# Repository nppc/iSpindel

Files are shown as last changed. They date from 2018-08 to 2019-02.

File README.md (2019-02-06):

# iSpindel - *DIY electronic Hydrometer*
# [www.ispindel.de](http://www.ispindel.de)

***
Dashboard
***



***

# Featured in german brewing magazine [Braumagazin.de](http://braumagazin.de/?issue=2018-01)
Braumagazin 1-18 (http://braumagazin.de/?issue=2018-01)

***

If you like that project please vote for the [Hackaday.io *2017 Prize List*](https://hackaday.io/project/20421-ispindel)

Check out [IOT DEVICE PULLS ITS WEIGHT IN HOME BREWING](http://hackaday.com/2017/03/01/iot-device-pulls-its-weight-in-home-brewing/)

## Documentation in other languages

### [English Documentation (work in progress)](docs/README_en.md) :us:
### [Nederlandse Vertaling (lopende werkzaamheden)](docs/README_nl.md) :nl:
### [Documentação em Português (trabalho em andamento)](docs/README_pt.md) :pt:

***

***Say thanks with a beer*** :beers:



***

## [Firmware download here](https://github.com/universam1/iSpindel/releases)

***

## ChangeLog

| Date | Note |
| :--- | :--- |
| 19.12.2018 | Firmware 6.0.4: Higher precision for polynominal possible |
| 19.12.2018 | Firmware 6.0.3: Higher precision for gravity displayed in status page |
| 24.10.2018 | Firmware 6.0.2: Display issues on MacOS resolved |
| 22.08.2018 | **Firmware 6.0.0**:<br>1. Alternative pin for OneWire tempearuture sensor DS18B20 now possible. This allows a different PCB schema to use either pin `D1` or `D6`. <br>2. Auto detection of OneWire pin, successfull detected pin will be saved together with a config `save` action. Output of detailed debug information of OneWire Sensor during searches, helping those with hardware issues. <br>3. Increased battery lifetime of about 20% by reducing the runtime to ~2200ms through various tunings.<br>4. Using *Interrupts* instead of delays to read the Accelerometer, allows significant shorter read intervals <br>5. Shorter read cycles allow  *more precision*, increased samples from 7 to 39 samples that still fit into the necessary wait state for the Temp sensor! |
| 16.08.2018 | Firmware 5.9.1: Fixing Ubidots issue and extending MQTT |
| 09.08.2018 | Firmware 5.9.0: Support for MQTT, InfluxDB (Thanks to jmelhus, iceaway and thorrak) |
| 13.05.2018 | Firmware 5.8.6: allow longer fields for polynominal, SSID and Password |
| 15.03.2018 | Firmware 5.8.5: adding support for Prometheus Pushgateway, thanks to @jankeesv |
| 08.03.2018 | Firmware 5.8.4: adding support for logging temperature data in Fahrenheit and Kelvin, thanks to @iceaway |
| 05.03.2018 | Firmware 5.8.3: Support for InfluxDB as additional backend, thanks to @iceaway |
| 23.02.2018 | New drawer version 'mwx-Edition' using threaded bolt nut and washer - thanks to @mwx |
| 21.02.2018 | Firmware 5.8.2: Extend token size to 40 char to support longer Ubidots token |
| 14.02.2018 | Firmware 5.8.1: HTML encode special character in configuration forms, allows displaying the passwort correctly |
| 09.02.2018 | Firmware 5.8.0: Transmitting the Wifi strength RSSI to insight of the reception |
| 07.02.2018 | Firmware 5.7.1: Allow longer sleep intervals longer up to 99999s == 27 days |
| 03.02.2018 | Firmware 5.7.0: Introduce Factory Reset feature |
| 02.02.2018 | Firmware 5.6.2: Support for Wifi credentials with special characters |
| 07.11.2017 | Firmware 5.6.1: Restoring Wifi credentials, moved to HTTP client library, improved RFCAL resilience to gain more stable Wifi connection |
| 17.10.2017 | Firmware 5.5.4: Various fixes for CraftBeerPi, BrewPiLess and Ubidots |
| 28.09.2017 | Firmware 5.5.0: Recall saved Wifi credential thus persisting over configuration changes |
| 31.08.2017 | iSpindle.py Version 1.3.1: genericTCP Update (local server & prep for public server); Firmware 5.4.2: Memory improvements. |
| 29.08.2017 | Firmware 5.4.1: Rewrite of the upload class to streamline and allow further data items. Also add iSpindel.de as data server as preset. |
| 08.08.2017 | [calibration tool](http://www.ispindel.de/tools/calibration/calibration.htm) to calculate gravity as alternative to the Excel sheet |
| 05.07.2017 | Workaround for BrewPiLess |
| 30.06.2017 | Mentioned in http://preview.mailerlite.com/g6n5p3/660851237247259035/r2w6/ |
| 22.05.2017 | updated build docs |
| 22.05.2017 | switching build environment to platform.io |
| 01.05.2017 | Major Firmware update to 5! Calculate the Gravity now within the iSpindel by expression evaluation! The conversion polynom can be stored per iSpindel and sends as an additional metric (without a unit). Therefore, whether Plato or SG is prefered is up to the user defined polynom. There are two variable available `tilt` and `temp`. Zero point calibration. Firmware update OTA over the Air |
| 12.04.2017 | Mentioned in http://www.homebrewtalk.com/showthread.php?t=598187 |
| 01.03.2017 | Mentioned in hackaday.com http://hackaday.com/2017/03/01/iot-device-pulls-its-weight-in-home-brewing/ |
| 23.02.2017 | English documentation added |
| 14.02.2017 | English documentation added |
| 09.02.2017 | Firmware 4.1.6 |
| 31.01.2017 | Bilder Aufbau Platinenvariante |
| 26.01.2017 | Firmware 4.0: inifinte sleep time developed: the maximum 71min RTC time extends through step-sleeps . Wifi RF calibration introduced when calling configuration. fixed bug of emergency interval. fixed UI numeric formating |
| 25.02.2017 | Firmware 3.5.0: genericTCP: Python Skript um lokal die Daten in eine CSV Datei zu schreiben (thanks to Tozzi) |
| 23.12.2016 | CraftBeerPi Info, FW.3.4.4, Combo-Schlitten |
| 18.12.2016 | FAQ und Ubidots tool |
| 15.11.2016 | Firmware 3.4.2: Supporting now backends: CraftBeerPi, TControl,FHEM, generic HTTP. major Portal rework, added labels for convenience, upload speed improvements, Power saving on empty battery, added custom Battery conversion factor, Bugfixes |
| 11.12.2016 | Sources and drawer online |
| 11.12.2016 | FHEM upload documentation & firmware (thanks @MSBannert!) |
| 07.12.2016 | Schematics |
| 03.12.2016 | Firmware 2.1.2 Wifi improvements |
| 09.11.2016 | Calibration and Excel sheet for conversion to Plato, SG etc. |

***

> Contribution and support is appreciated especially regarding creation and translation of documentation. Feel free to provide a `pull request`.  
>
> Die `iSpindel` befindet sich in andauernder Entwicklung, siehe dazu [den Hobbybrauer.de Thread](http://hobbybrauer.de/forum/viewtopic.php?f=7&t=11235). Mithilfe ist herzlich willkommen und Ergänzungen bitte per Pull Request einreichen. Großes Dank an alle die Unterstützung leisten seitens Grundlagen erarbeiten oder passende Hardware zu finden.

## Inhaltverzeichnis

- [Lizenz](#lizenz)
- [Prinzip](#prinzip)
  - [Metazentrum](#metazentrum)
- [Aufbau](#aufbau)
  - [Varianten](#varianten)
  - [Bauteile](#bauteile)
  - [Schaltplan](#schaltplan)
  - [Schlitten](#schlitten)
- [Konfiguration](#konfiguration)
  - [Ubidots](#ubidots)
  - [Portal](#portal)
  - [Scripting](#scripting)
- [Software](#software)
  - [Firmware Update](#firmware-flashen-from-source)
  - [Compile](#compile-from-source)
- [Anzeige](#anzeige)
  - [Kalibrierung der Spindel](#kalibrierung)
  - [Ubidots Graphen](#ubidots-graphen)
  - [CraftBeerPi](#craftbeerpi)
  - [FHEM](#fhem)
  - [iSpindel TCP Server](#ispindel-tcp-server)
- [FAQ](docs/FAQ.md)
- [Software](#software)

***

## Lizenz

> Jeglicher kommerzieller Nachbau oder Verwendung ist prinzipiell untersagt. Geltende Patente werden verletzt.
>
> All rights reserverd, any commercial use is hereby prohibited and will violate applicable patents.

***

## Prinzip

Die Messung der Dichte von Wasser mit Hilfe des krängenden Zylinders ist so einfach wie genial - man braucht keine externe Referenz (außer der Erde) und der Zylinder ist extrem leicht sauber zu halten. Der Neigungswinkel ändert sich im Verhältnis zum Auftrieb und damit im direkten Zusammenhang mit dem Zuckergehalt.
Kein unnötiges Öffnen zum spindeln und evtl. Kontaminieren!

Kränung

Daher die Idee, ein IoT device mit Wifi zusammen mit einem Beschleunigungssensor und Temperatursensor in einen schwimmenden Zylinder zu legen. Dort wacht er alle bsp. 5min auf, verbindet sich mit meinem Wlan und sendet seinen Neigungswinkel, Temperatur und Akkuspannung an einen Cloudservice wie [Ubidots](www.ubidots.com) oder einen lokalen Server.

### *Metazentrum*

Eigentlich dreht es sich hier um das "Metazentrum", der Zylinder wird solange rotieren bis das Metazentrum im Lot zum Auftriebspunkt ist. Diesen Wert messen wir.

Man kann insofern trimmen, dass man am Boden ein paar Gramm hinzufügt, damit stellt sich der Zylinder mehr auf, oder am Deckel, damit krängt er mehr. 

In der Software berechnent man aus den XYZ Beschleunigungswerten den Euler Winkel für X und Y und bildet daraus den Absolutwinkel. Diesen verrechnen wir mit den kalibrierten Eckwerten zum °Plato.

***

## Aufbau

### Varianten

> Alle drei Varianten sind funktionell identisch

1. [Variante A: Lochrasterplatine & Schlitten](docs/iSpindelbreadboard.md)  
Die Lochrasterplatine ermöglicht den Nachbau jederzeit mit 'Hausmitteln' 
1. [Variante B: nur Platine](docs/iSpindelPCB.md)  
Die fertige Platine über die Sammelbestellung bringt einen komfortablen Aufbau
1. [Variante C: Platine & Schlitten](docs/iSpindelPCB.md)  
Die obige Platine kann (über Trenn-Schnitt) mit dem Kunstoff Schlitten in Kombination verwendet werden der einen spielfreien Sitz garantiert.

### Bauteile

***siehe [Bauteile](docs/Parts.md)***

### Schaltplan

***siehe [Schaltplan](docs/Schaltplan.md)***

### Schlitten

***siehe [Bauteile](docs/Parts.md)***

***

## Konfiguration

### Ubidots

- Zu Beginn muss ein kostenloser Account bei [Ubidots.com](https://ubidots.com) erstellt werden
- Im Menü  `API Credentials` erhält man seinen `Token` durch das die iSpindel die Berechtigung zum Schreiben der Daten erhält.  
***Diesen notieren.***  

Token

### Portal

Durch mehrmaliges Drücken der `Reset Taste` erstellt der Wemos einen AccessPoint, mit dem verbunden man die nötigen Einstellugen vornehmen kann.

> Die `iSpindel` signalisiert dass sie sich im *Konfiguration-Modus* druch permanentes Blinken im Sekundentakt.  
Man verlässt den *Konfiguration-Modus* durch speichern seiner Einstellungen, durch betätigen des Menüpunkts `Start iSpindel` oder durch warten von 5 Minuten. Danach befindet sie sich im *Betriebsmodus* d.h. sie sendet ihre Daten und geht daraufhin direkt in den "Deep Sleep" Standby Modus. Daher ist sie im normalen Modus nicht erreibar.

- Der Ubidots  `Token` ~~und die  `IDs`~~, welche man oben notiert hat, werden nun an dieser Stelle eingetragen.  

- Ebenfalls stellt man hier den `Intervall` ein in dem sie Daten liefert. Dies hat direkt mit der Akku Lebensdauer zu tun. Es empfiehlt sich in der Praxis etwa `1800` Sekunden (= 30 Minuten) Takt zu wählen.

   Setup

- Man erreicht es über

   AccessPointPortal

- Eine Übersicht der Daten kann man über den `Info` Menüpunkt einsehen

  Info

Nach dem man obige Daten eingetragen und gespeichert hat, wird die Spindel sich mit dem Wlan und Ubidots verbinden und die Daten übertragen.  
Falls noch nicht vorhanden, wird selbständig ein neues `Device` erstellt und die Sensoren angelegt.  
Auf der Ubidots Weboberfläche wird man nun unter `Sources` sehen dass die Daten aktualisiert werden.  

Nun kann man im `Dashboard` sich seine Graphen nach Belieben zusammenstellen.

### Scripting

Ubidots kann ausserdem an vielen Stellen per Script bedient werden. Eine Dokumentation zu den Funktionen findet sich direkt bei Ubidots. Hiermit können zum Beispiel nicht mehr benötigte Daten in Variablen gelöscht werden.

- [siehe Ubidots-Scripting](docs/ubidotsscripting.md)

***
## Anzeige

Die `iSpindel` kann ihre Daten an verschieden backends senden. Es empfiehlt sich mit dem Cloudservice [Ubidots](www.Ubidots.com) zu beginnen, dort kann man sich einen kostenlosen Account erstellen und die Graphen sich darstellen. Man kann auch weitere Abwandlungen der Daten vornehmen, wie den Plato / SG Wert errechnen, den EVG usw.
Folgende backends werden mittlerweile unterstützt:

### Ubidots Graphen

- [Plato Formel](docs/Kalibrierung.md#formel)

### CraftBeerPi

> Beschreibung von @not:  
*Wenn Du die neueste Firmware auf Deine iSpindel geflasht hast musst Du auch craftbeerpi updaten: dazu brauchst Du den branch "hydrometer". Wenn Du die Spindel dann konfigurierst, gibst Du neben den Einstellungen für Dein WLAN im Dropdown-Menu "CraftbeerPi" an und darunter die IP Adresse Deines im selben Netzwerk gelegenen Craftbeerpi-Servers.
Danach sendet die Spindel an den Raspberry Pi -Rechner und Craftbeerpi registriert die Spindel automatisch . Wenn die Verbindung klappt, findest Du die Spindel "wie von Geisterhand" in der Hardware-Konfiguration von CBP.
Du siehst, dass Daten ankomen, wenn Du Deine Fermentation / Gärung im CBP anschaust, da sind dann nicht nur die Temperatur (ist und soll) , sondern auch Spindeltemperatur und Plato zu sehen (siehe Screenshot oben) mit letztem Zeitstempel.*  
`git clone -b hydrometer https://github.com/Manuel83/craftbeerpi.git`

### FHEM

- [upload zu FHEM](docs/upload-FHEM.md)

### iSpindel-TCP-Server

- [https://github.com/DottoreTozzi/iSpindel-TCP-Server](https://github.com/DottoreTozzi/iSpindel-TCP-Server)

***

## Kalibrierung

Zur Umrechnung von dem gemessenen **Winkel ° in °Plato, SG, %mas** o.ä. ist es initial nötig eine Referenzkurve zu kalibrieren. 
Die gewonnenen Referenzen können dann über eine Excel Tabelle oder das [Online Gravity Calibration tool](http://www.ispindel.de/tools/calibration/calibration.htm) in eine Funktion überführt werden, die zur Darstellung hinterlegt wird. 

Da jede selbstgebaute Spindel andere Messwerte ergeben wird, muss man diesen Prozess einmalig pro iSpindel durchführen.

[siehe Kalibrierung durchführen](docs/Kalibrierung.md)

***

## Software 

### Firmware flashen

- [Firmware flashen](docs/Firmware.md)

### Compile from Source

- [Compile from source](docs/compile.md)

***Gefällt es dir, na dann spende mir halt ein Bier***  :beers:



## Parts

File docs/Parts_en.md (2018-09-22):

# Parts

Following parts are required:

### Plastic cylinder

- plastic cylinder `Petling` [Petling-XL](http://cachers-world.de/de/Petling-XL)
> The provider [cachers-world.de](http://cachers-world.de/de/Petling-XL) supports this project by providing the appropriate petling in the long term and using the coupon code "` HOBBYBRAUER` "( Capitalization!) 20% discount granted.
This [Petling-XL](http://cachers-world.de/de/Petling-XL) fits the 3D printed sled.

***

### drawer

- plastic drawer [download](https://github.com/universam1/iSpindel/raw/master/drawer/)

This is also offered by an online dispatch

***https://3d-mechatronics.de/en/ispindel-diy-set-komplett_151.html***

> *** There is no business relationship between me and the provider, this is a pure help. ***

Sled
***
### Battery pack

- `18650 LiIo cell` (e.g.,` Panasonic NCR18650B`)

***

### Components

- [Wemos D1 mini](https://wiki.wemos.cc/products:d1:d1_mini)
- `GY-521` Gyro & Acceleration Sensor (MPU-6050 on suitable breakout board)
- [DS18B20 Temperature Sensor](https://www.maximintegrated.com/en/products/analog/sensors-and-sensor-interface/DS18B20.html)
- Square grid 3x4cm or printed circuit board
- Resistors
  - 4k7 ohms
  - 220k ohms
  - 330 ohms or BAT43 diode
- [microswitches](http://www.reichelt.de/Schiebeschalter/SS-ESP201/3/index.html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)
Or at the PCB [Reed Wechsler](http://www.reichelt.de/Reedrelais/KSK-1C90/3/index.html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)
- Lipo charger `TP4056` (6 pin recommended)

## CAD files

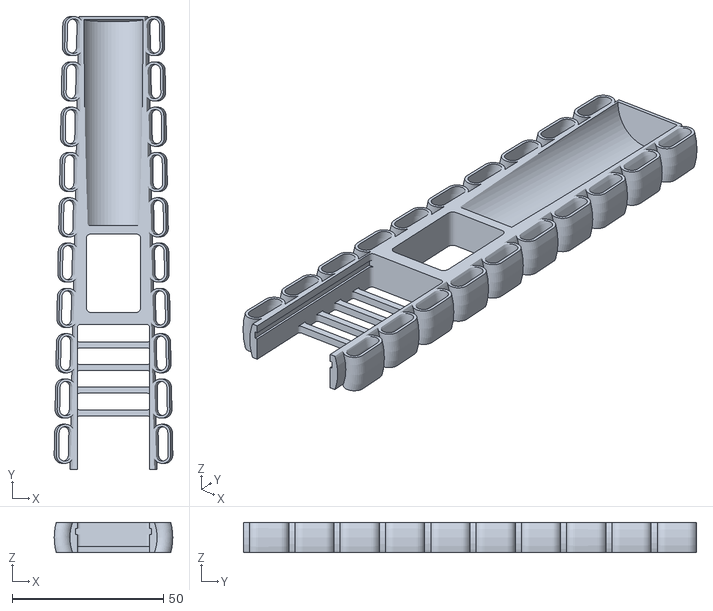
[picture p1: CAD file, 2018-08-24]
drawer/25mmPCB/Sled.stl
39.3 x 150.0 x 10.0

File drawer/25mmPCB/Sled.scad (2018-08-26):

// PCB is 25x48mm

$fn = 80;
length = 148; // normally is 150, but I have too much weight at the end, so it doesn't fit.
diamchange = 2.73; // smaller 4mm each 10cm
diam1 = 40.1;
diam2 = diam1-(length/100*diamchange); 
echo(diam1);
echo(diam2);


difference(){
    mainpart();
    translate([0,99,-15])cube([50,200,20],true);
    translate([0,99,15])cube([50,200,20],true);
    CutOut(24,53*2,2);
    translate([0,47.5/2+5,2])cube([25.3,48.5,1.85],true); // for PCB
    translate([0,147,2])rotate([86,0,0])liion(); //battery
    translate([0,66,0])CutOut(22,23,4);
}
translate([0,42,-5])underPCB();


module liion(){
    cylinder(d=19.5,h=68,$fn=50);
}


module roundcut(radius, width, rlen){
    minkowski(){
    union(){
        difference(){
            cylinder(r=radius,h=20,$fn=50);
            translate([0.2,-width+1.5,0])cylinder(r=radius,h=20,$fn=50);
            translate([rlen-1.5,-radius,0])cube([radius*2,radius*2,20]);
            translate([-radius*3,-width,0])cube([radius*3,radius*3,20]);
        }
    }
    cylinder(d=1.5,h=20,$fn=15);
    }
}

module CutOut(cw,cl,cdiam) {
  cwd=cw-cdiam;
  clw=cl-cdiam;
  hull(){
    translate([cwd/2,clw/2,0])cylinder(d=cdiam,h=20,$fn=20,center=true);
    translate([-cwd/2,clw/2,0])cylinder(d=cdiam,h=20,$fn=20,center=true);
    translate([cwd/2,-clw/2,0])cylinder(d=cdiam,h=20,$fn=20,center=true);
    translate([-cwd/2,-clw/2,0])cylinder(d=cdiam,h=20,$fn=20,center=true);
  }
}

module underPCB(){
    difference(){
        translate([0,1,1])cube([25,22,2],true);
        for(i=[0:7.5:27])translate([0,i-17,0])CutOut(24,5.5,1.5);
    }

}

module donut(diamext,diamint){
    rotate_extrude(convexity = 10)
    translate([(diamext-(diamext-diamint)/2)/2, 0, 0])
    circle(d = (diamext-diamint)/2, $fn = 30);
}


module mainpart() {
  translate([0, length, 0]) 
  rotate([90, 0, 0])
  union() {
    cylinder(d2=diam1-11,d1=diam2-11, h=length);
    for(i=[0:16.5:140])
       translate([0,0,i])spring(diam2+(i/100*diamchange),14,5.5,0.8);
  }
}

module spring(sdiam, slen, sh, thck){
    difference(){
        spring_sub(sdiam,slen,sh);
        translate([0,0,thck])spring_sub(sdiam-thck*2,slen-thck*2,sh-thck*2);
    }
}
    
module spring_sub(sdiam,slen,sh){
    sdiam2 = sdiam-((slen-sh)/100*diamchange);
    difference(){
        translate([0,0,sh/2])cylinder(d2=sdiam, d1=sdiam2,h=slen-sh);
        translate([0,0,sh/2])cylinder(d2=sdiam-sh*2, d1=sdiam2-sh*2,h=slen-sh);
    }
    translate([0,0,sh/2])donut(sdiam2,sdiam2-sh*2);
    translate([0,0,slen-sh/2])donut(sdiam,sdiam-sh*2);
}

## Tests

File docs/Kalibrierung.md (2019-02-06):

# Kalibrierung

>Zur Umrechnung von Winkel ° in °Plato, SG, %mas o.Ä. ist es initial nötig eine Referenzkurve zu kalibrieren. Die gewonnenen Referenzen können dann vereinfacht über eine Excel Tabelle in eine Funktion überführt werden, die zur Darstellung hinterlegt wird. Da jede selbstgebaute Spindel andere Messwerte ergeben wird, muss man diesen Prozess einmalig durchführen.

>Stelle sicher dass die iSpindel im normalen Wasser ca. 25° Neigung von der Vertikalen aufweist. Gegebenenfalls noch weiter austarieren. Meistens sind ca. 20g an zusätzlichem Gewicht nötig.

***

# Inhalt

- [Kalibrierung](#kalibrierung)
- [Inhalt](#inhalt)
  - [Variante A (vereinfacht)](#variante-a-vereinfacht)
  - [Variante B Schnellvergärung (genauer)](#variante-b-schnellverg%C3%A4rung-genauer)
  - [Variante C Referenzen ziehen (empfohlen)](#variante-c-referenzen-ziehen-empfohlen)
- [Formel](#formel)
- [Speichern](#speichern)
  - [in iSpindel hinterlegen](#in-ispindel-hinterlegen)
  - [Alternativ: in Ubidots nach-berechnen](#alternativ-in-ubidots-nach-berechnen)

***

## Variante A (vereinfacht)

> Zum Ablessen des Neigungswinkels empfiehlt es sich, die iSpindel mit Ubidots zu verbinden und einen sehr kurzen Intervall (20 Sekunden) zu setzen. Damit kann die Neigung über die Webseite verfolgt werden.  
>  
>  Alternativ: Im Konfigurationsmodus kann die ```Info``` Seite aufgerufen werden und dort den Winkel abgelesen werden.

1. iSpindel in Reinwasser 0 °Plato legen, ***Winkel notieren (sollte ca. 25° Neigung aus der Vertikalen sein)***
2. Zuckerwasser mit ca. 20 °Plato herstellen, oder höchsten Wert den man voraussichtlich erreichen wird. ***Plato messen und Winkel notieren***  
*Beispiel 400ml Wasser + 100g Kristallzucker auflösen*
1. Wasser weiter verdünnen auf ca. 15 °Plato, ***Plato messen und Winkel notieren***   
*Beispiel +166ml Wasser hinzufügen*
1. Wasser weiter verdünnen auf ca. 10 °Plato, ***Plato messen und Winkel notieren***   
*Beispiel +333ml Wasser hinzufügen*
1. Wasser weiter verdünnen auf ca. 7,5 °Plato, ***Plato messen und Winkel notieren***   
*Beispiel +333ml Wasser hinzufügen*
1. Wasser weiter verdünnen auf ca. 5 °Plato, ***Plato messen und Winkel notieren***   
*Beispiel +666ml Wasser hinzufügen*
1. Wasser weiter verdünnen auf ca. 2,5 °Plato, ***Plato messen und Winkel notieren***   
*Beispiel +2000ml Wasser hinzufügen*

**gemessene Werte werden in das [Excel Sheet](#formel) eingetragen** 

***

## Variante B Schnellvergärung (genauer)

**Diese Variante ist genauer, da der CO2 Auftriebsfehler mit ein - kalibriert wird**

> Zum Ablessen des Neigungswinkels empfiehlt es sich, die iSpindel mit Ubidots zu verbinden und einen sehr kurzen Intervall (20 Sekunden) zu setzen. Damit kann die Neigung über die Webseite verfolgt werden.  

1. iSpindel in Reinwasser 0 °Plato legen, ***Winkel notieren (sollte ca. 25° Neigung aus der Vertikalen sein)***
1. Zuckerwasser mit ca. 20 °Plato herstellen, oder höchsten Wert den man voraussichtlich erreichen wird.  
*Beispiel 800ml Wasser + 200g Kristallzucker auflösen*
1. Hefe hinzufügen und Spindel einlegen. ***Plato messen und Winkel notieren*** 
1. bis x. :  Nun nimmt man regelmässig Plato Messwerte und den jeweilig korrelierenden Winkel und trägt dies in die Excel Tabelle ein. 
> Achtung: Sollte man hier einen Refraktometer verwenden darf man die Korrektur dessen nicht vergessen: [Refraktometerrechner](http://www.maischemalzundmehr.de/index.php?inhaltmitte=toolsrefraktorechner)

## Variante C Referenzen ziehen (empfohlen)

> Die einfachste und vermeintlich genaueste Variante ist sie in eine Gärung zu bringen und einige Referenzen zu ziehen. Man notiert sich die Stammwürze und den entsprechenden Winkel den man zB. bei Ubidots zu diesem Zeitpunkt sieht. Im Verlauf der Gärung nimmt man weiter 3 oder mehr solcher Referenzen ( gespindelte Stammwürze / Winkel ) notiert diese bis zum Gärende. Damit erhält man praxisnahe Werte die übrigens den CO2 Einfluss beinhalten bzw. berücksichtigen.
Danach kann man mit dem errechnen der Formel fortfahren, und diesen fest in der iSpindel dann hinterlegen.

***

# Formel
Folgende Varianten existieren um das Polynome leicht zu errechnen:

- ## [Online Gravity Calibration tool](http://www.ispindel.de/tools/calibration/calibration.htm)

Die Messwerte werden in das Feld `Plato` oder `Brix` eingetragen mit dem korrespondierendem Neigungswinkel unter `Tilt`. Daraus errechnet sich dann ein Polynom 2. oder 3. Grades welches dann in der Firmware hinterlegt wird.

***

- ## Excel Tabelle

> Obige Meßwerte können nun anhand dieser Excel Tabelle in eine annähernde Formel überführt werden.  
Diese hinterlegt man in Ubidots um die Anzeige des °Plato zu erhalten.  
> Andere Darstellung wie EVG, %mas, SG, Alc. werden nach gleichem Prinzip über eine ```Derived``` Variable aus vorhandenen Werten errechnet

1. Die obigen Meßwerte in die Excel Tabelle eintragen  
  [Download Excel Tabelle](Kalibrierung.xlsm)
1. ```Formel update``` Macro durch den Button starten, stellt die Trendlinie als Formal dar  
Formel update

# Speichern

## in iSpindel hinterlegen

> Das Polynome kann nun in der iSpindel gespeichert werden, welcher in Laufzeit evaluiert und berechnet wird. Damit liefert die iSpindel nun die Dichte direkt als Datensatz.

Plato

## Alternativ: in Ubidots nach-berechnen

1. Ubidots eine ```Derived``` Variable erstellen, d.h. eine berechnete die auf anderen Daten aufbaut.  
1. Bei Ubidots auf Sources gehen
1. Source ISpindel wählen
1. (+) Add variable wählen
1. Derived wählen 
1. Dort kann dann die Excel Formel eingetragen werden.  
```tilt``` ersetzt man durch ```instert Variable``` und wählt dort ```tilt``` aus 
![Plato](/pics/Ubiplato.jpg)
1. Im ```Dashboard``` erstellt man dann einen neuen Graphen mit den Datenquelle ```Plato```

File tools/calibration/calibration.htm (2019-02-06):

iSpindel Calibration

Gravity Unit: Measurement: Reading: Temperature Corrected. Wort Temperature CAL@ Reading:°P @Wort Correction: Tilt: SG: Plato: °P Add Data

| Tilt | Plato SG | Degree 2 Value | Degree 2 Error | Degree 3 Value | Degree 3 Error
Degree 2:
Degree 3:

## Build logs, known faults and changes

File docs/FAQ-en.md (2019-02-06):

# Questions and answers FAQ

- ***Do I have to tare the iSpindle with weights?***  
It is indispensable to enable the iSpindle functionality! Add weights such as nuts, lead balls etc. to the bottom  until the inclination is 25° from the vertical. See also example pictures in the documentation. Normally about 20g are sufficient. +/- 5° deviations are often still acceptable.

- ***It doesn't work, I don't see anything***  
The best way to find out what the iSpindle is doing as information is to read it's log. This can be done via a serial monitor like HTerm or Arduino IDE. Connect the spindle via Micro USB, then open the Com Port with the serial monitor above and read it. Set baud rate to `115200`. It brings light into the dark.

Here is a youtube howto: https://youtu.be/6xDW5GbIbUw

- ***How get to the iSpindel - the portal***  
Switch it on, press the reset button 3-4 times which sets up an access point. That means you will see a new Wifi network "iSpindel" where you connect to with your computer, smartphone or tablet. Now the browser should automatically redirect you to the page[http://192.168.4.1](http://192.168.4.1). If not, navigate there yourself.
If you are now on the portal page, under `Configuration` you can enter your token and the wifi password that you need for your network. Then click on `safe` and it will send the data to Ubidots. This means that the **iSpindel is not reachable in normal operation**, until you manually start the portal again.

- ***Why can't I access the iSpindle in normal operation***  
The critical part of the battery life time is that the iSpindle is active as short as possible and maximum time being in`deep sleep`! The Wemos in active operation requires more than 300x of energy, so this trick is indispensable to achieve the runtime.

- ***The Micro USB port is for program updates?***
Correct, see Firmware Update

- ***How can I calibrate the voltage display?***
From firmware 3.0 on you can adjust the conversion factor. By default, factor 191.8 is used. You can adjust by this formula:
````
(displayed voltage / measured voltage) * current factor (191.8) = new factor

The new factor should be between current factor more or less 20% (191.8*0.8 - 191.8*1.2).
````
- ***Can I operate it in a stainless steel container? Is it possible to get through the faradic cage?***
To achieve a sufficient WLAN signal strength you can do the following things:

  - Break open the faradic cage. This is possible by electrically separating the lid from the pot. Can be achieved by applying a silicone sealant between the two parts.
  - Use a passive antenna. Use a shielded cable that is stripped from both ends (i. e. Lambda/4), where one side ends in the pot, exactly 3.2mm. This is transmitted passively from the inside to the outside and vice versa. A good example can be found here: http://hobbybrauer.de/forum/viewtopic.php?p=208782#p208782
  - Install a wifi range extender next to the barrel to increase the signal level.

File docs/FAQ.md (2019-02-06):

# Fragen und Antworten FAQ

- ***Muss ich die iSpindel mit Gewichten tarieren?***  
Dies ist unabdingbar um die Funktion der iSpindel überhaupt zu ermöglichen! Füge am Boden des Petlings Gewichte wie Muttern, Bleikugeln o.ä. hinzu bis die Neigung 25° von der Vertikalen beträgt. Siehe dazu auch Beispielbilder in der Dokumentation. Normalerweise sind etwa 20g ausreichend. +/- 5° Abweichung sind oft noch akzeptabel.

- ***Es funktioniert nicht, ich sehe nichts***  
Am Besten du liest mit was die Spindel als Informationen ausgiebt. Das geht über einen Serial Monitor wie HTerm oder Arduino. Die Spindel per Micro USB anschliessen, dann den Com Port mit obigen Serial Monitor öffnen und mitlesen, Baud `115200`. 
Ein Youtube HowTo: https://youtu.be/6xDW5GbIbUw

- ***Wie komme ich auf die iSpindel - das Portal***  
Anschalten, 3-4 maliges drücken der Reset Taste stellt sie einen Access Point auf. D.h. du siehst ein neues WLAN "iSpindel" mit dem du dich verbindest. Jetzt wirst den Browser automatisch auf die Seite [http://192.168.4.1](http://192.168.4.1) dich weiterleiten. Falls nicht steuer sie selbst an.
Wenn du nun auf der Portalseite bist, unter `Configuration` dann kannst du deinen Token eingeben und das WLAN Passwort dass du für dein Netzwerk benötigst. dann klickst du auf `safe` und sie wird ihre Daten an Ubidots senden. Damit ist sie im Normalbetrieb und nicht mehr zu erreichen

- ***mein Wlan-Passwort bleibt nicht gespeichert***  
Das ist korrekt, wenn man das Portal wieder startet (reset Taste) werden die Wlan Daten gelöscht. Zur Zeit so implementiert.

- ***Wenn die Spindel außerhalb des Sekundenintvallblinkmodus ist, kann ich sie erst wieder erreichen wenn ich die Resettaste betätigt habe***  
Reset Taste wäre nur sinnvoll wenn man was ändern möchte. Normalerweise wacht sie selber auf nach dem Intervall und geht in 'Normalbetrieb'. 
Man kann die Spindel im Normalbetrieb _nicht_ erreichen, sie sendet ausschließlich. (Powermanagement)

- ***Warum kann ich auf die iSpindel nicht im Normalbetrieb zugreifen***  
Der kritische Teil der Laufzeit ist dass die iSpindel so kurz wie nur möglich aktiv ist und sich die maximale Zeit im `deep sleep`  befindet! Der Wemos im Aktiv - Betrieb hat einen über 300x Energiebedarf, um daher die Laufzeit zu erreichen ist dieser Trick unumgänglich.
- ***Die Micro USBBuchse ist für Programmaktualisierungen?***
Korrekt, siehe Firmwareaktualisierung
- ***Wie kann ich die Spannungsanzeige kalibrieren?***
Ab Firmware 3 kann man den Umrechnungfaktor anpassen. Standardmässig ist der Faktor 191.8, diesen umrechnen:
```
angezeigte Spannung / gemessene Spannung  * jetziger Faktor (191.8) = neuer Faktor
```
- ***Kann ich sie in einem Edelstahl Behälter betreiben? Geht es auch durch den faradischen Käfig?***
Um eine ausreichende WLAN Signalstärke zu erreichen kann man z.B. folgende Dinge unternehmen:

  - Den faradischen Käfig aufbrechen. Dies ist möglich, indem man den Deckel vom Topf elektrisch trennt. Kann durch Aufbringen einer Silikondichtmasse zwischen die beiden Teile erreicht werden.
  - Eine passive Antenne einsetzen. Benutzen Sie ein abgeschirmtes Kabel, das von beiden Enden (d. h. Lambda/4), wo eine Seite im Topf endet, exakt 3,2mm abgemantelt ist. Diese wird passiv von innen nach außen und umgekehrt übertragen. Ein gutes Beispiel gibt es hier: http://hobbybrauer.de/forum/viewtopic.php?p=208782#p208782
  - Einen Wifi Range Extender direkt neben dem Fass installieren, um den Signalpegel zu erhöhen.

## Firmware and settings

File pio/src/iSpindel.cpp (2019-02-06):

/**************************************************************

"iSpindel"
All rights reserverd by S.Lang <universam@web.de>

**************************************************************/

// includes go here
#include <PubSubClient.h>
#include "Globals.h"
#include "MPUOffset.h"
// #endif
#include "OneWire.h"
#include "Wire.h"
// #include <Ticker.h>
#include "DallasTemperature.h"
#include "DoubleResetDetector.h" // https://github.com/datacute/DoubleResetDetector
#include "RunningMedian.h"
#include "WiFiManagerKT.h"
#include <ArduinoJson.h> //https://github.com/bblanchon/ArduinoJson
#include <DNSServer.h>
#include <ESP8266WebServer.h>
#include <ESP8266WiFi.h> //https://github.com/esp8266/Arduino
#include <FS.h>          //this needs to be first
#include "tinyexpr.h"

#include "Sender.h"
// !DEBUG 1

// definitions go here
MPU6050_Base accelgyro;
OneWire *oneWire;
DallasTemperature DS18B20;
DeviceAddress tempDeviceAddress;
Ticker flasher;
RunningMedian samples = RunningMedian(MEDIANROUNDSMAX);
DoubleResetDetector drd(DRD_TIMEOUT, DRD_ADDRESS);

#define TEMP_CELSIUS 0
#define TEMP_FAHRENHEIT 1
#define TEMP_KELVIN 2

int detectTempSensor(const uint8_t pins[]);
bool testAccel();

#ifdef USE_DMP
#include "MPU6050.h"

// MPU control/status vars
bool dmpReady = false;  // set true if DMP init was successful
uint8_t mpuIntStatus;   // holds actual interrupt status byte from MPU
uint8_t devStatus;      // return status after each device operation (0 = success, !0 = error)
uint16_t packetSize;    // expected DMP packet size (default is 42 bytes)
uint16_t fifoCount;     // count of all bytes currently in FIFO
uint8_t fifoBuffer[64]; // FIFO storage buffer

// orientation/motion vars
Quaternion q;        // [w, x, y, z]         quaternion container
VectorInt16 aa;      // [x, y, z]            accel sensor measurements
VectorInt16 aaReal;  // [x, y, z]            gravity-free accel sensor measurements
VectorInt16 aaWorld; // [x, y, z]            world-frame accel sensor measurements
VectorFloat gravity; // [x, y, z]            gravity vector
float euler[3];      // [psi, theta, phi]    Euler angle container
float ypr[3];        // [yaw, pitch, roll]   yaw/pitch/roll container and gravity vector
#endif

bool shouldSaveConfig = false;

char my_token[TKIDSIZE * 2];
char my_name[TKIDSIZE] = "iSpindel000";
char my_server[TKIDSIZE];
char my_url[TKIDSIZE];
char my_db[TKIDSIZE] = "ispindel";
char my_username[TKIDSIZE];
char my_password[TKIDSIZE];
char my_job[TKIDSIZE] = "ispindel";
char my_instance[TKIDSIZE] = "000";
char my_polynominal[100] = "-0.00031*tilt^2+0.557*tilt-14.054";

String my_ssid;
String my_psk;
uint8_t my_api;
uint32_t my_sleeptime = 15 * 60;
uint16_t my_port = 80;
float my_vfact = ADCDIVISOR;
int16_t my_aX = UNINIT, my_aY = UNINIT, my_aZ = UNINIT;
uint8_t my_tempscale = TEMP_CELSIUS;
int8_t my_OWpin = -1;

uint32_t DSreqTime = 0;
float pitch, roll;

int16_t ax, ay, az;
float Volt, Temperatur, Tilt, Gravity; // , corrGravity;

//bool DSrequested = false;

#ifdef LED_EXT
bool ledState;
#endif

float scaleTemperature(float t)
{
  if (my_tempscale == TEMP_CELSIUS)
    return t;
  else if (my_tempscale == TEMP_FAHRENHEIT)
    return (1.8f * t + 32);
  else if (my_tempscale == TEMP_KELVIN)
    return t + 273.15f;
  else
    return t; // Invalid value for my_tempscale => default to celsius
}

String tempScaleLabel(void)
{
  if (my_tempscale == TEMP_CELSIUS)
    return "C";
  else if (my_tempscale == TEMP_FAHRENHEIT)
    return "F";
  else if (my_tempscale == TEMP_KELVIN)
    return "K";
  else
    return "C"; // Invalid value for my_tempscale => default to celsius
}

// callback notifying us of the need to save config
void saveConfigCallback()
{
  shouldSaveConfig = true;
}

void applyOffset()
{
  if (my_aX != UNINIT && my_aY != UNINIT && my_aZ != UNINIT)
  {
    CONSOLELN(F("applying offsets"));
    accelgyro.setXAccelOffset(my_aX);
    accelgyro.setYAccelOffset(my_aY);
    accelgyro.setZAccelOffset(my_aZ);
  }
  else
    CONSOLELN(F("offsets not available"));
}

bool readConfig()
{
  CONSOLE(F("mounting FS..."));

  if (SPIFFS.begin())
  {
    CONSOLELN(F(" mounted!"));
    if (SPIFFS.exists(CFGFILE))
    {
      // file exists, reading and loading
      CONSOLELN(F("reading config file"));
      File configFile = SPIFFS.open(CFGFILE, "r");
      if (configFile)
      {
        size_t size = configFile.size();
        // Allocate a buffer to store contents of the file.
        std::unique_ptr<char[]> buf(new char[size]);

        configFile.readBytes(buf.get(), size);
        DynamicJsonBuffer jsonBuffer;
        JsonObject &json = jsonBuffer.parseObject(buf.get());

        if (json.success())
        {
          if (json.containsKey("Name"))
            strcpy(my_name, json["Name"]);
          if (json.containsKey("Token"))
            strcpy(my_token, json["Token"]);
          if (json.containsKey("Server"))
            strcpy(my_server, json["Server"]);
          if (json.containsKey("Sleep"))
            my_sleeptime = json["Sleep"];
          if (json.containsKey("API"))
            my_api = json["API"];
          if (json.containsKey("Port"))
            my_port = json["Port"];
          if (json.containsKey("URL"))
            strcpy(my_url, json["URL"]);
          if (json.containsKey("DB"))
            strcpy(my_db, json["DB"]);
          if (json.containsKey("Username"))
            strcpy(my_username, json["Username"]);
          if (json.containsKey("Password"))
            strcpy(my_password, json["Password"]);
          if (json.containsKey("Job"))
            strcpy(my_job, json["Job"]);
          if (json.containsKey("Instance"))
            strcpy(my_instance, json["Instance"]);
          if (json.containsKey("Vfact"))
            my_vfact = json["Vfact"];
          if (json.containsKey("TS"))
            my_tempscale = json["TS"];
          if (json.containsKey("OWpin"))
            my_OWpin = json["OWpin"];
          if (json.containsKey("SSID"))
            my_ssid = (const char *)json["SSID"];
          if (json.containsKey("PSK"))
            my_psk = (const char *)json["PSK"];
          if (json.containsKey("POLY"))
            strcpy(my_polynominal, json["POLY"]);

          my_aX = UNINIT;
          my_aY = UNINIT;
          my_aZ = UNINIT;

          if (json.containsKey("aX"))
            my_aX = json["aX"];
          if (json.containsKey("aY"))
            my_aY = json["aY"];
          if (json.containsKey("aZ"))
            my_aZ = json["aZ"];
          applyOffset();

          CONSOLELN(F("parsed config:"));
#ifdef DEBUG
          json.printTo(Serial);
          CONSOLELN();
#endif
          return true;
        }
        else
        {
          CONSOLELN(F("ERROR: failed to load json config"));
          return false;
        }
      }
      CONSOLELN(F("ERROR: unable to open config file"));
    }
  }
  else
  {
    CONSOLELN(F(" ERROR: failed to mount FS!"));
    return false;
  }
  return true;
}

bool shouldStartConfig(bool validConf)
{

  // we make sure that configuration is properly set and we are not woken by
  // RESET button
  // ensure this was called

  rst_info *_reset_info = ESP.getResetInfoPtr();
  uint8_t _reset_reason = _reset_info->reason;

  // The ESP reset info is sill buggy. see http://www.esp8266.com/viewtopic.php?f=32&t=8411
  // The reset reason is "5" (woken from deep-sleep) in most cases (also after a power-cycle)
  // I added a single reset detection as workaround to enter the config-mode easier
  CONSOLE(F("Boot-Mode: "));
  CONSOLELN(ESP.getResetReason());
  bool _poweredOnOffOn = _reset_reason == REASON_DEFAULT_RST || _reset_reason == REASON_EXT_SYS_RST;
  if (_poweredOnOffOn)
    CONSOLELN(F("power-cycle or reset detected, config mode"));

  bool _dblreset = drd.detectDoubleReset();
  if (_dblreset)
    CONSOLELN(F("\nDouble Reset detected"));

  // Seems ESP-07S has a valid reset info (6 for power on and 5 for reset)
  if (_reset_reason==6) {
    // on first boot initialize WiFi. Needed for ESP-07S
    CONSOLELN();
    CONSOLELN(F("Initialize WiFi"));
//    WiFi.begin();
    WiFi.disconnect();
    delay(1000);
    WiFi.begin(my_ssid.c_str(), my_psk.c_str());
    WiFi.waitForConnectResult();
  }

  bool _wifiCred = (WiFi.SSID() != "");
  uint8_t c = 0;
  if (!_wifiCred)
    WiFi.begin();
  while (!_wifiCred)
  {
    if (c > 10)
      break;
    CONSOLE('.');
    delay(100);
    c++;
    _wifiCred = (WiFi.SSID() != "");
  }
  if (!_wifiCred)
    CONSOLELN(F("\nERROR no Wifi credentials"));

  if (validConf && !_dblreset && _wifiCred && !_poweredOnOffOn)
  {
    CONSOLELN(F("\nwoken from deepsleep, normal mode"));
    return false;
  }
  // config mode
  else
  {
    CONSOLELN(F("\ngoing to Config Mode"));
    return true;
  }
}

void validateInput(const char *input, char *output)
{
  String tmp = input;
  tmp.trim();
  tmp.replace(' ', '_');
  tmp.toCharArray(output, tmp.length() + 1);
}

String htmlencode(String str)
{
  String encodedstr = "";
  char c;

  for (uint16_t i = 0; i < str.length(); i++)
  {
    c = str.charAt(i);

    if (isalnum(c))
    {
      encodedstr += c;
    }
    else
    {
      encodedstr += "&#";
      encodedstr += String((uint8_t)c);
      encodedstr += ';';
    }
  }
  return encodedstr;
}

bool startConfiguration()
{

  WiFiManager wifiManager;

  wifiManager.setConfigPortalTimeout(PORTALTIMEOUT);
  wifiManager.setSaveConfigCallback(saveConfigCallback);
  wifiManager.setBreakAfterConfig(true);

  WiFiManagerParameter api_list(HTTP_API_LIST);
  WiFiManagerParameter custom_api("selAPI", "selAPI", String(my_api).c_str(),
                                  20, TYPE_HIDDEN, WFM_NO_LABEL);

  WiFiManagerParameter custom_name("name", "iSpindel Name", htmlencode(my_name).c_str(),
                                   TKIDSIZE * 2);
  WiFiManagerParameter custom_sleep("sleep", "Update Interval (s)",
                                    String(my_sleeptime).c_str(), 6, TYPE_NUMBER);
  WiFiManagerParameter custom_token("token", "Token", htmlencode(my_token).c_str(),
                                    TKIDSIZE * 2 * 2);
  WiFiManagerParameter custom_server("server", "Server Address",
                                     my_server, TKIDSIZE);
  WiFiManagerParameter custom_port("port", "Server Port",
                                   String(my_port).c_str(), TKIDSIZE,
                                   TYPE_NUMBER);
  WiFiManagerParameter custom_url("url", "Server URL", my_url, TKIDSIZE);
  WiFiManagerParameter custom_db("db", "InfluxDB db", my_db, TKIDSIZE);
  WiFiManagerParameter custom_username("username", "Username", my_username, TKIDSIZE);
  WiFiManagerParameter custom_password("password", "Password", my_password, TKIDSIZE);
  WiFiManagerParameter custom_job("job", "Prometheus job", my_job, TKIDSIZE);
  WiFiManagerParameter custom_instance("instance", "Prometheus instance", my_instance, TKIDSIZE);
  WiFiManagerParameter custom_vfact("vfact", "Battery conversion factor",
                                    String(my_vfact).c_str(), 7, TYPE_NUMBER);
  WiFiManagerParameter tempscale_list(HTTP_TEMPSCALE_LIST);
  WiFiManagerParameter custom_tempscale("tempscale", "tempscale",
                                        String(my_tempscale).c_str(),
                                        5, TYPE_HIDDEN, WFM_NO_LABEL);

  wifiManager.addParameter(&custom_name);
  wifiManager.addParameter(&custom_sleep);
  wifiManager.addParameter(&custom_vfact);

  WiFiManagerParameter custom_tempscale_hint("<label for=\"TS\">Unit of temperature</label>");
  wifiManager.addParameter(&custom_tempscale_hint);
  wifiManager.addParameter(&tempscale_list);
  wifiManager.addParameter(&custom_tempscale);
  WiFiManagerParameter custom_api_hint("<hr><label for=\"API\">Service Type</label>");
  wifiManager.addParameter(&custom_api_hint);

  wifiManager.addParameter(&api_list);
  wifiManager.addParameter(&custom_api);

  wifiManager.addParameter(&custom_token);
  wifiManager.addParameter(&custom_server);
  wifiManager.addParameter(&custom_port);
  wifiManager.addParameter(&custom_url);
  wifiManager.addParameter(&custom_db);
  wifiManager.addParameter(&custom_username);
  wifiManager.addParameter(&custom_password);
  wifiManager.addParameter(&custom_job);
  wifiManager.addParameter(&custom_instance);
  WiFiManagerParameter custom_polynom_lbl("<hr><label for=\"POLYN\">Gravity conversion<br/>ex. \"-0.00031*tilt^2+0.557*tilt-14.054\"</label>");
  wifiManager.addParameter(&custom_polynom_lbl);
  WiFiManagerParameter custom_polynom("POLYN", "Polynominal", htmlencode(my_polynominal).c_str(), 100 * 2, WFM_NO_LABEL);
  wifiManager.addParameter(&custom_polynom);

  wifiManager.setConfSSID(htmlencode(my_ssid));
  wifiManager.setConfPSK(htmlencode(my_psk));

  CONSOLELN(F("started Portal"));
  wifiManager.startConfigPortal("iSpindel");

  strcpy(my_polynominal, custom_polynom.getValue());

  validateInput(custom_name.getValue(), my_name);
  validateInput(custom_token.getValue(), my_token);
  validateInput(custom_server.getValue(), my_server);
  validateInput(custom_db.getValue(), my_db);
  validateInput(custom_username.getValue(), my_username);
  validateInput(custom_password.getValue(), my_password);
  validateInput(custom_job.getValue(), my_job);
  validateInput(custom_instance.getValue(), my_instance);
  my_sleeptime = String(custom_sleep.getValue()).toInt();

  my_api = String(custom_api.getValue()).toInt();
  my_port = String(custom_port.getValue()).toInt();
  my_tempscale = String(custom_tempscale.getValue()).toInt();
  validateInput(custom_url.getValue(), my_url);

  String tmp = custom_vfact.getValue();
  tmp.trim();
  tmp.replace(',', '.');
  my_vfact = tmp.toFloat();
  if (my_vfact < ADCDIVISOR * 0.8 || my_vfact > ADCDIVISOR * 1.2)
    my_vfact = ADCDIVISOR;

  // save the custom parameters to FS
  if (shouldSaveConfig)
  {
    // Wifi config
    WiFi.setAutoConnect(true);
    WiFi.setAutoReconnect(true);

    return saveConfig();
  }
  return false;
}

void formatSpiffs()
{
  CONSOLE(F("\nneed to format SPIFFS: "));
  SPIFFS.end();
  SPIFFS.begin();
  CONSOLELN(SPIFFS.format());
}

bool saveConfig()
{
  CONSOLE(F("saving config..."));

  // if SPIFFS is not usable
  if (!SPIFFS.begin() || !SPIFFS.exists(CFGFILE) ||
      !SPIFFS.open(CFGFILE, "w"))
    formatSpiffs();

  DynamicJsonBuffer jsonBuffer;
  JsonObject &json = jsonBuffer.createObject();

  json["Name"] = my_name;
  json["Token"] = my_token;
  json["Sleep"] = my_sleeptime;
  // first reboot is for test
  my_sleeptime = 1;
  json["Server"] = my_server;
  json["API"] = my_api;
  json["Port"] = my_port;
  json["URL"] = my_url;
  json["DB"] = my_db;
  json["Username"] = my_username;
  json["Password"] = my_password;
  json["Job"] = my_job;
  json["Instance"] = my_instance;
  json["Vfact"] = my_vfact;
  json["TS"] = my_tempscale;
  json["OWpin"] = my_OWpin;

  // Store current Wifi credentials
  json["SSID"] = WiFi.SSID();
  json["PSK"] = WiFi.psk();

  json["POLY"] = my_polynominal;
  json["aX"] = my_aX;
  json["aY"] = my_aY;
  json["aZ"] = my_aZ;

  File configFile = SPIFFS.open(CFGFILE, "w+");
  if (!configFile)
  {
    CONSOLELN(F("failed to open config file for writing"));
    SPIFFS.end();
    return false;
  }
  else
  {
#ifdef DEBUG
    json.printTo(Serial);
#endif
    json.printTo(configFile);
    configFile.close();
    SPIFFS.end();
    CONSOLELN(F("saved successfully"));
    return true;
  }
}

bool processResponse(String response)
{
  DynamicJsonBuffer jsonBuffer;
  JsonObject &json = jsonBuffer.parseObject(response);

  if (json.success() && json.containsKey("interval"))
  {
    uint32_t interval = json["interval"];
    if (interval != my_sleeptime &&
        interval < 24 * 60 * 60 &&
        interval > 10)
    {
      my_sleeptime = interval;
      CONSOLE(F("Received new Interval config: "));
      CONSOLELN(interval);
      return saveConfig();
    }
  }
  return false;
}

bool uploadData(uint8_t service)
{
  SenderClass sender;

#ifdef API_UBIDOTS
  if (service == DTUbiDots)
  {
    sender.add("tilt", Tilt);
    sender.add("temperature", scaleTemperature(Temperatur));
    sender.add("battery", Volt);
    sender.add("gravity", Gravity);
    sender.add("interval", my_sleeptime);
    sender.add("RSSI", WiFi.RSSI());
    CONSOLELN(F("\ncalling Ubidots"));
    return sender.sendUbidots(my_token, my_name);
  }
#endif

#ifdef API_MQTT
  if (service == DTMQTT)
  {
    sender.add("tilt", Tilt);
    sender.add("temperature", scaleTemperature(Temperatur));
    sender.add("temp_units", tempScaleLabel());
    sender.add("battery", Volt);
    sender.add("gravity", Gravity);
    sender.add("interval", my_sleeptime);
    sender.add("RSSI", WiFi.RSSI());
    CONSOLELN(F("\ncalling MQTT"));
    return sender.sendMQTT(my_server, my_port, my_username, my_password, my_name);
  }
#endif

#ifdef API_INFLUXDB
  if (service == DTInfluxDB)
  {
    sender.add("tilt", Tilt);
    sender.add("temperature", scaleTemperature(Temperatur));
    sender.add("temp_units", tempScaleLabel());
    sender.add("battery", Volt);
    sender.add("gravity", Gravity);
    sender.add("interval", my_sleeptime);
    sender.add("RSSI", WiFi.RSSI());
    CONSOLELN(F("\ncalling InfluxDB"));
    CONSOLELN(String(F("Sending to db: ")) + my_db + String(F(" w/ credentials: ")) + my_username + String(F(":")) + my_password);
    return sender.sendInfluxDB(my_server, my_port, my_db, my_name, my_username, my_password);
  }
#endif

#ifdef API_PROMETHEUS
  if (service == DTPrometheus)
  {
    sender.add("tilt", Tilt);
    sender.add("temperature", Temperatur);
    sender.add("battery", Volt);
    sender.add("gravity", Gravity);
    sender.add("interval", my_sleeptime);
    sender.add("RSSI", WiFi.RSSI());
    CONSOLELN(F("\ncalling Prometheus Pushgateway"));
    return sender.sendPrometheus(my_server, my_port, my_job, my_instance);
  }
#endif

#ifdef API_GENERIC
  if ((service == DTHTTP) || (service == DTCraftBeerPi) || (service == DTiSPINDELde) || (service == DTTCP))
  {

    sender.add("name", my_name);
    sender.add("ID", ESP.getChipId());
    if (my_token[0] != 0)
      sender.add("token", my_token);
    sender.add("angle", Tilt);
    sender.add("temperature", scaleTemperature(Temperatur));
    sender.add("temp_units", tempScaleLabel());
    sender.add("battery", Volt);
    sender.add("gravity", Gravity);
    sender.add("interval", my_sleeptime);
    sender.add("RSSI", WiFi.RSSI());

    if (service == DTHTTP)
    {
      CONSOLELN(F("\ncalling HTTP"));
      return sender.sendGenericPost(my_server, my_url, my_port);
    }
    else if (service == DTCraftBeerPi)
    {
      CONSOLELN(F("\ncalling CraftbeerPi"));
      return sender.sendGenericPost(my_server, CBP_ENDPOINT, 5000);
    }
    else if (service == DTiSPINDELde)
    {
      CONSOLELN(F("\ncalling iSPINDELde"));
      return sender.sendTCP("ispindle.de", 9501);
    }
    else if (service == DTTCP)
    {
      CONSOLELN(F("\ncalling TCP"));
      String response = sender.sendTCP(my_server, my_port);
      return processResponse(response);
    }
  }
#endif // DATABASESYSTEM

#ifdef API_FHEM
  if (service == DTFHEM)
  {
    sender.add("angle", Tilt);
    sender.add("temperature", scaleTemperature(Temperatur));
    sender.add("temp_units", tempScaleLabel());
    sender.add("battery", Volt);
    sender.add("gravity", Gravity);
    sender.add("ID", ESP.getChipId());
    CONSOLELN(F("\ncalling FHEM"));
    return sender.sendFHEM(my_server, my_port, my_name);
  }
#endif // DATABASESYSTEM ==
#ifdef API_TCONTROL
  if (service == DTTcontrol)
  {
    sender.add("T", scaleTemperature(Temperatur));
    sender.add("D", Tilt);
    sender.add("U", Volt);
    sender.add("G", Gravity);
    CONSOLELN(F("\ncalling TCONTROL"));
    return sender.sendTCONTROL(my_server, my_port);
  }
#endif // DATABASESYSTEM ==
  return false;
}

void goodNight(uint32_t seconds)
{

  uint32_t _seconds = seconds;
  uint32_t left2sleep = 0;
  uint32_t validflag = RTCVALIDFLAG;

  drd.stop();

  // workaround for DS not floating
  pinMode(my_OWpin, OUTPUT);
  digitalWrite(my_OWpin, LOW);

  // we need another incarnation before work run
  if (_seconds > MAXSLEEPTIME)
  {
    left2sleep = _seconds - MAXSLEEPTIME;
    ESP.rtcUserMemoryWrite(RTCSLEEPADDR, &left2sleep, sizeof(left2sleep));
    ESP.rtcUserMemoryWrite(RTCSLEEPADDR + 1, &validflag, sizeof(validflag));
    CONSOLELN(String(F("\nStep-sleep: ")) + MAXSLEEPTIME + "s; left: " + left2sleep + "s; RT: " + millis());
    ESP.deepSleep(MAXSLEEPTIME * 1e6, WAKE_RF_DISABLED);
  }
  // regular sleep with RF enabled after wakeup
  else
  {
    // clearing RTC to mark next wake
    left2sleep = 0;
    ESP.rtcUserMemoryWrite(RTCSLEEPADDR, &left2sleep, sizeof(left2sleep));
    ESP.rtcUserMemoryWrite(RTCSLEEPADDR + 1, &validflag, sizeof(validflag));
    CONSOLELN(String(F("\nFinal-sleep: ")) + _seconds + "s; RT: " + millis());
    // WAKE_RF_DEFAULT --> auto reconnect after wakeup
    ESP.deepSleep(_seconds * 1e6, WAKE_RF_DEFAULT);
  }
  // workaround proper power state init
  delay(500);
}
void sleepManager()
{
  uint32_t left2sleep, validflag;
  ESP.rtcUserMemoryRead(RTCSLEEPADDR, &left2sleep, sizeof(left2sleep));
  ESP.rtcUserMemoryRead(RTCSLEEPADDR + 1, &validflag, sizeof(validflag));

  // check if we have to incarnate again
  if (left2sleep != 0 && !drd.detectDoubleReset() && validflag == RTCVALIDFLAG)
  {
    goodNight(left2sleep);
  }
  else
  {
    CONSOLELN(F("Worker run!"));
  }
}

void requestTemp()
{
  if (!DSreqTime)
  {
    DS18B20.requestTemperatures();
    DSreqTime = millis();
  }
}
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
void loop()
{
  CONSOLELN(F("should never be here!"));
}

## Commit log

2018-07-27 Added external blink support D2 pin
2018-08-19 Mine drawer
    [Sled.scad, Sled.stl]
2018-08-20 adjusting sled
    [Sled.scad]
2018-08-20 sled modified
    [Sled.scad, Sled.stl]
2018-08-21 Detection of DS18b20 pin
2018-08-24 sled is reworked
    [Sled.scad, Sled.stl]
2018-08-26 Final version of drawer
    [Sled.scad]
